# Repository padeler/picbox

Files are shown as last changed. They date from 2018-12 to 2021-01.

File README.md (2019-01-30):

# picbox
Arduino based Photo album and sketch toy. 
Simple functionality for browsing the photos on the SD card and sketching in different colors.

# Notes
In order to keep the code small enough to fit into the 28k of the arduino micro 
I stripped the TFTLCD library and kept only the functionality I needed.

The code looks for "bmp" photos in the "/album" folder of the SD Card and 
displays them starting from a random point on each boot.

Top (navigation) buttons are (from left to right) 
- show previous
- show random
- reload
- show next

Bottom buttons select the pen color for sketching.

Toy case created with OpenSCAD and printed with PLA.

## Hardware used
- Arduino pro micro (leonardo) 5V
- TF-028 TFT touch screen (240x320) shield with sd-card
- 2x18650 Batteries in series (because I had some spare)
- Power switch
- Prototyping PCB 

## External Libraries
- [TFTLCD-Library](https://github.com/adafruit/TFTLCD-Library)
- [SdFat](https://github.com/greiman/SdFat)

## Making-of Photos
PCB, arduino and LCD+touchscreen+SDCard_reader shield. Front and back views
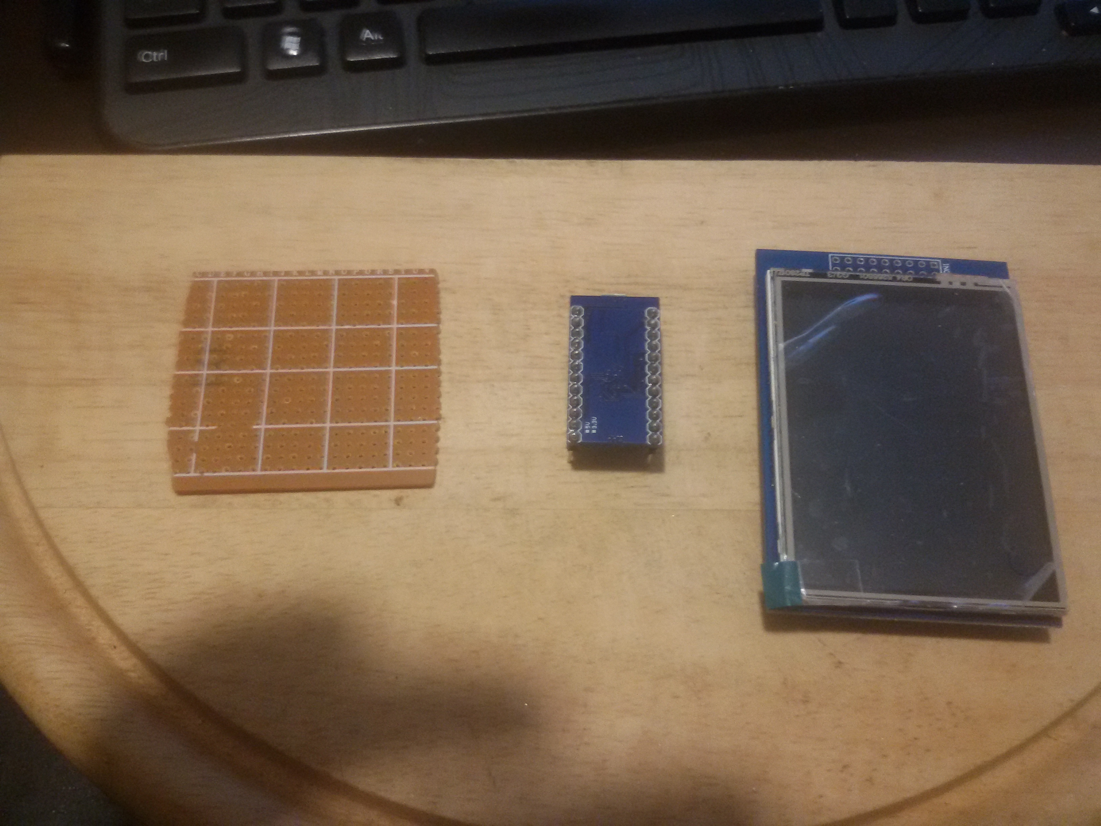
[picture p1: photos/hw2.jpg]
hw2

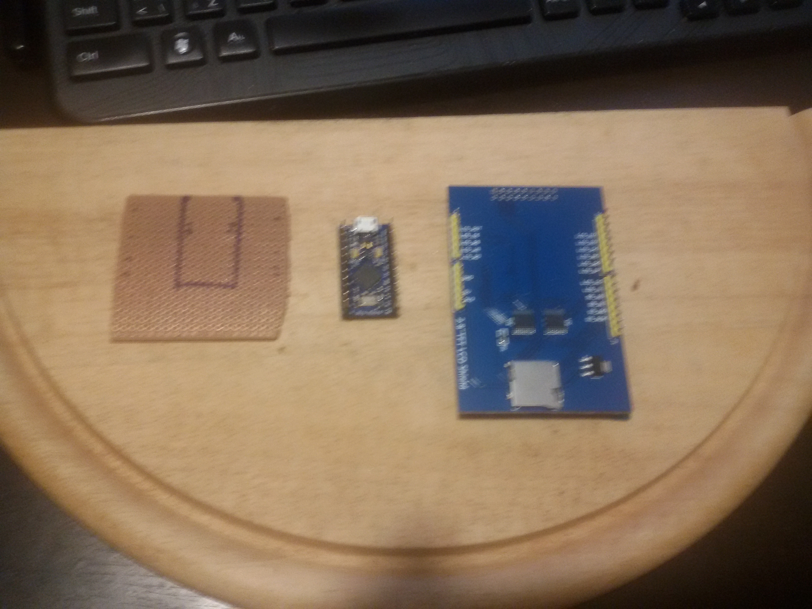
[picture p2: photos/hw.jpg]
hw

In order to save space the arduino goes between the PCB and the LCD board.
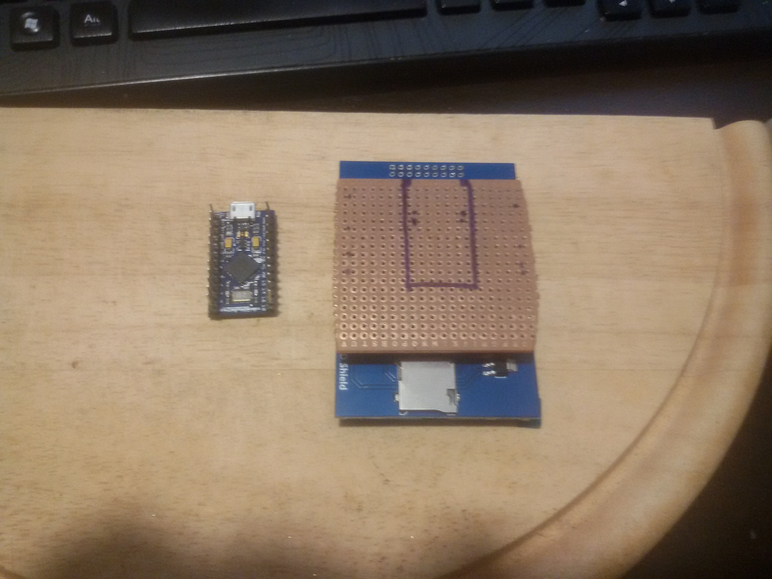
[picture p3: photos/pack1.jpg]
pack1

After soldering the arduino to the PCB. It is a bit messy but it was my first try using a PCB this way.
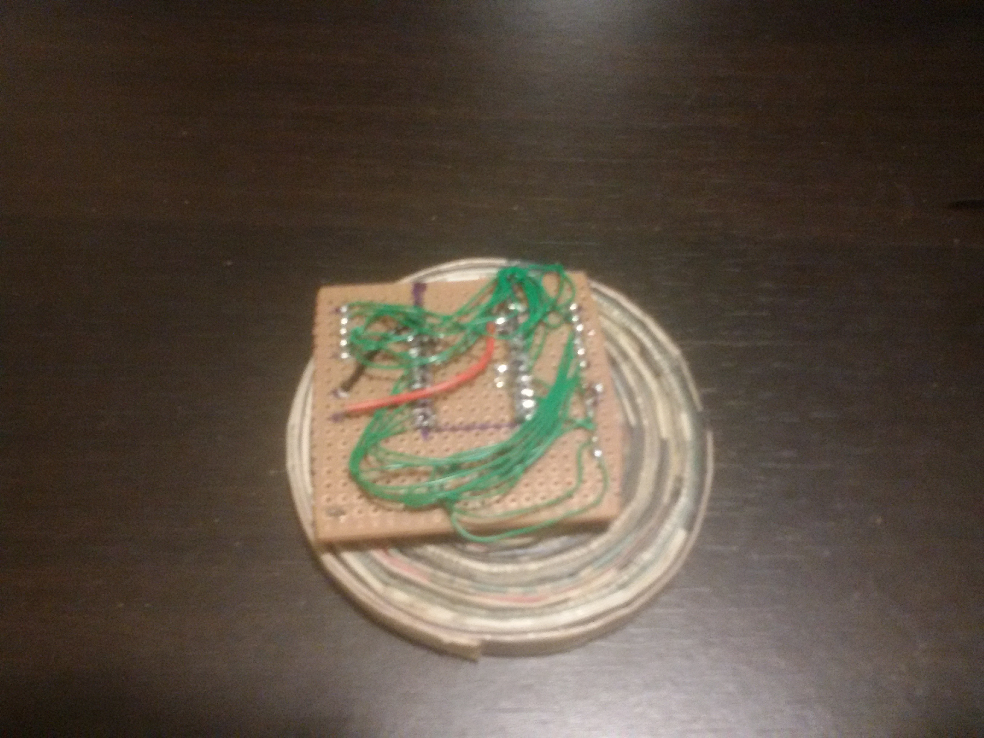
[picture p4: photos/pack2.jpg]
pack2

Testing basic h/w and s/w functionality.
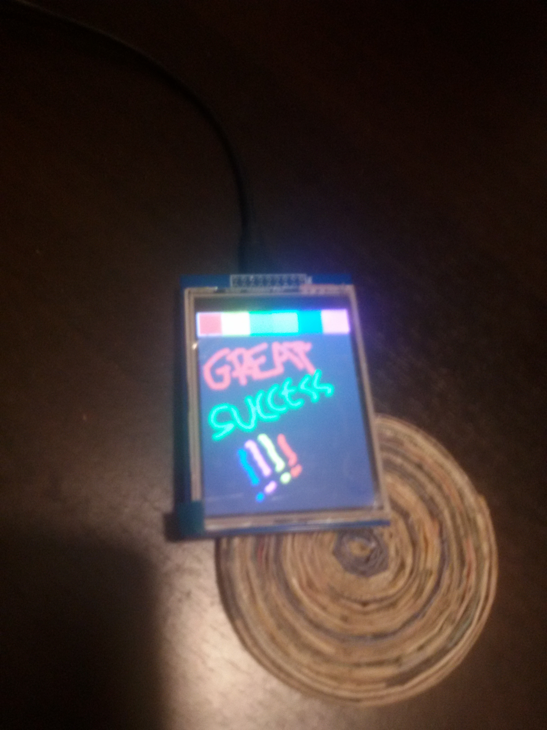
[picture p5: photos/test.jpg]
test

Assempling everything into the 3D printed case. Orange is a nice color for a little girl's toy :)
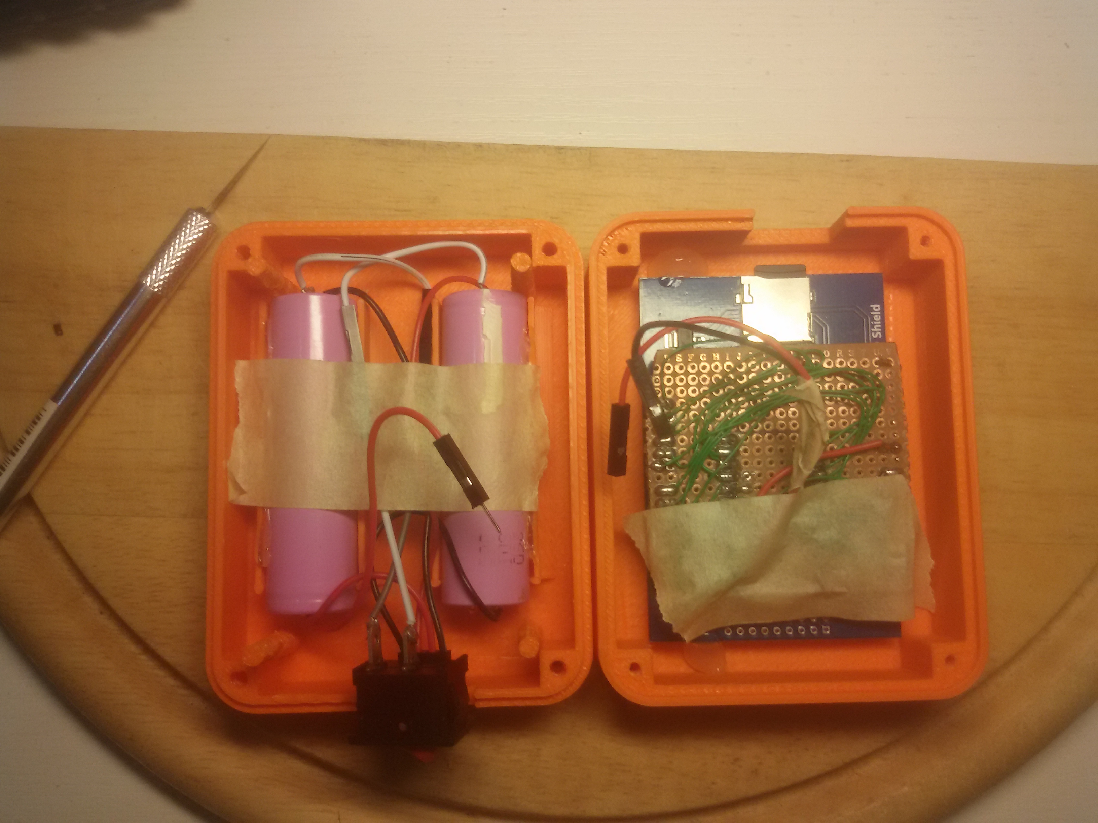
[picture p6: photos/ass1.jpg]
ass1

Another view of the box. Since this is a kids toy, I secured all h/w in place with some hot glue. Maybe it will survive a few more hits this way!
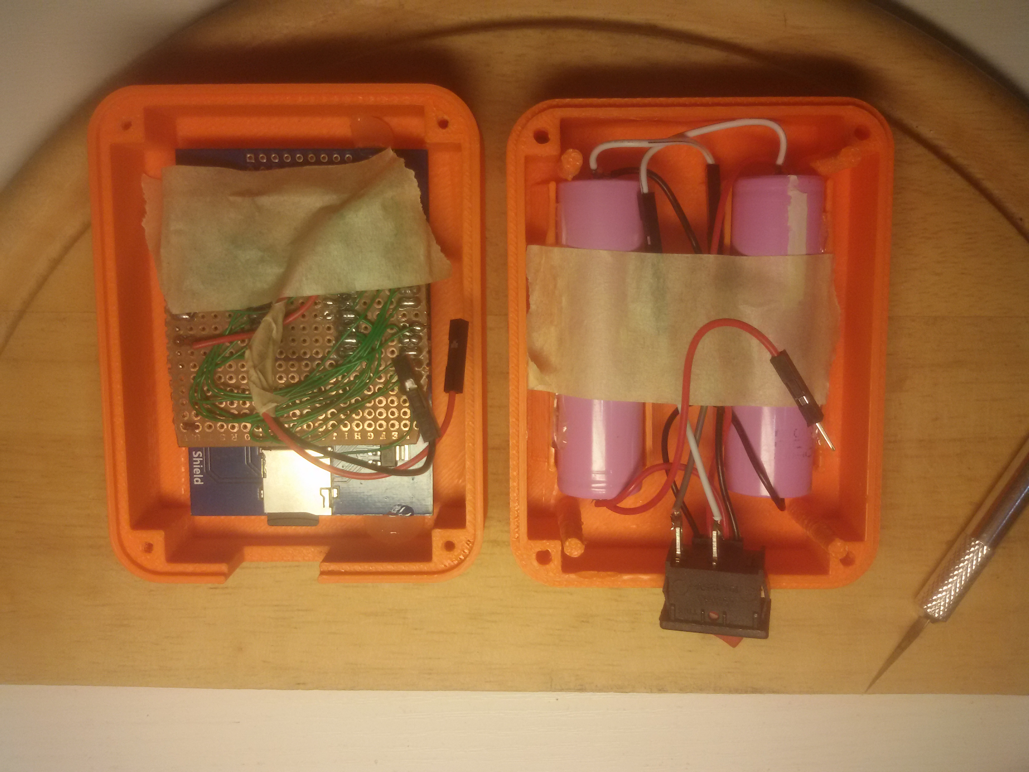
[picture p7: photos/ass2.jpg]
ass2

And this is the end result. The use of 18650 batteries made it a bit thicker than it would be if I had opted for for 2xAAA batteries and 3V H/W. But it has a pretty long battery life now!
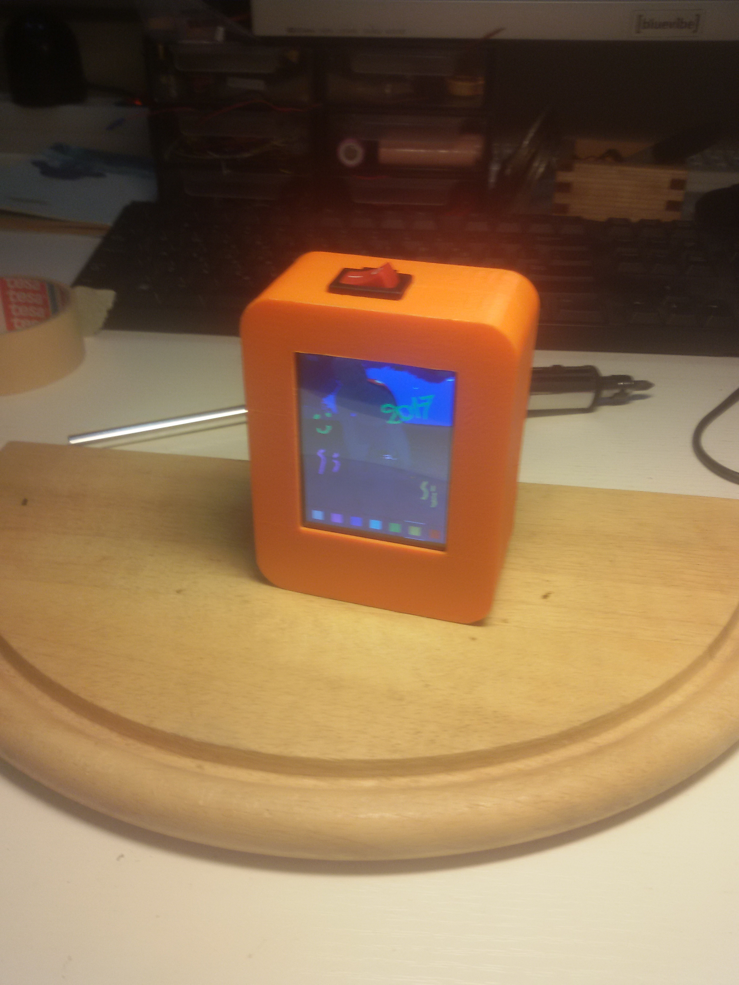
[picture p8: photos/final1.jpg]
final1
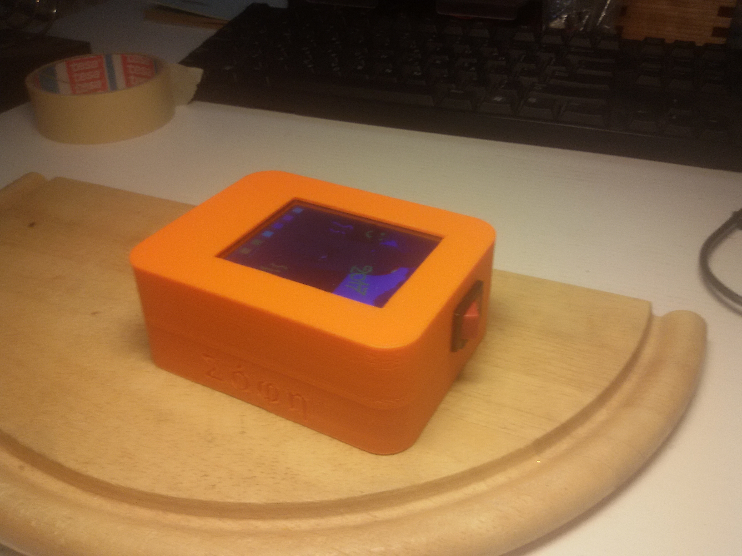
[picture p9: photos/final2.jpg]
final2
 
And a closeup of the screen showing the interface
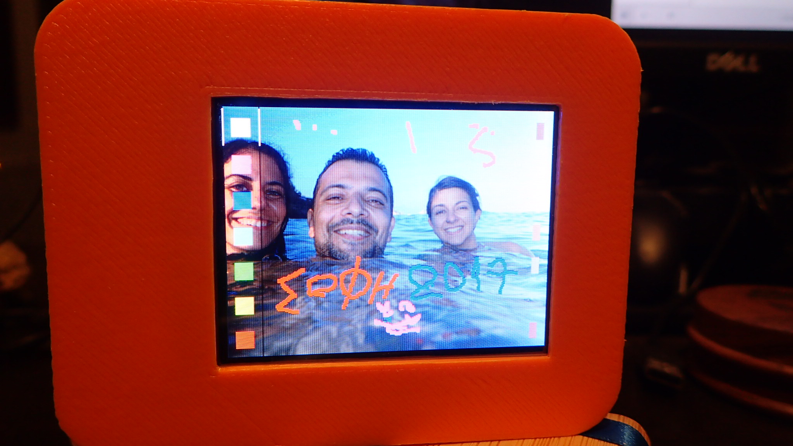
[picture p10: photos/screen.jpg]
screen


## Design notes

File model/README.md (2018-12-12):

# picbox case

The models in this folder are based on the
[3D-Printed-Case-for-Arduino](https://github.com/zygmuntw/3D-Printed-Case-for-Arduino) project.

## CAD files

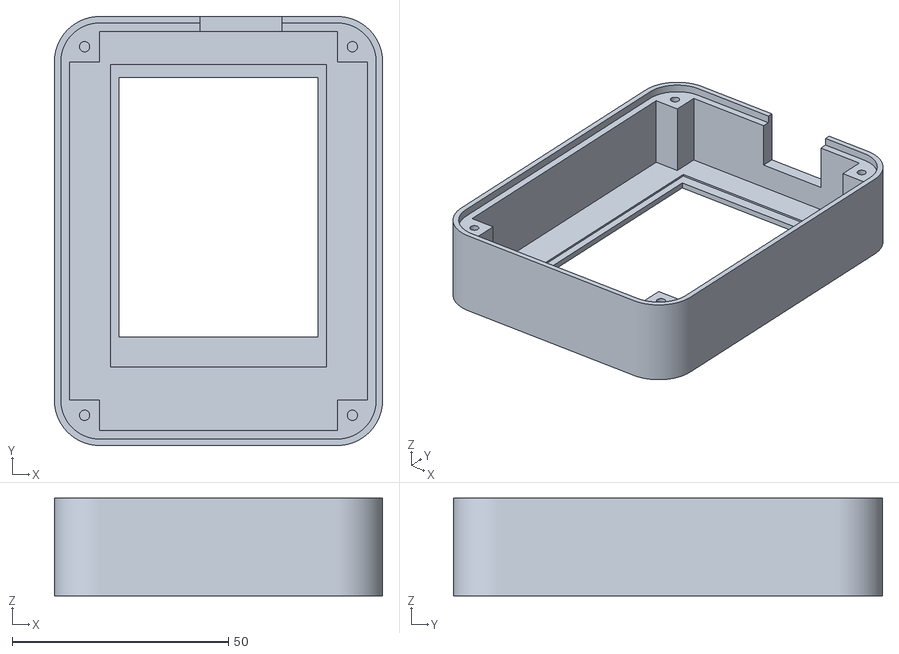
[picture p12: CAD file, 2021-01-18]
model/top.stl
76.0 x 99.3 x 22.6

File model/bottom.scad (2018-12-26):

//  ----------------------------------------------------------------------- LICENSE
//  This "3D Printed Case for Arduino Uno, Leonardo" by Zygmunt Wojcik is licensed
//  under the Creative Commons Attribution-ShareAlike 3.0 Unported License.
//  To view a copy of this license, visit
//  http://creativecommons.org/licenses/by-sa/3.0/
//  or send a letter to Creative Commons, PO Box 1866, Mountain View, CA 94042, USA.


include <common.scad>


//------------------------------------------------------------------------- MAIN BLOCK
module bottom(){
    difference()
    {
        // ADD
        union()
        {
            // Add Base
            linear_extrude(height = height/2, convexity = 10)
            minkowski()
            {									
                square([width, wide], center = true);
                circle(roundR);
            }
        }
        // SUBSTRACT
        union()
        {
            // Lift floor height
            // Cut Base hole
            translate([0, 0, floorHeight])
            linear_extrude(height = height/2, convexity = 10)
            minkowski()
            {
                square([width, wide], center = true);
                circle(roundR - pillarSize);
            }
            // Cut upper block lock
            difference() {
                translate([0, 0, height/2 - blockLockSize ]) {
                    linear_extrude(height = blockLockSize+2, convexity = 10)
                    minkowski() {
                        square([width+1, wide+1], center=true);
                        circle(roundR);
                    }
                }
                translate([0, 0, height/2 - blockLockSize ]) {
                    linear_extrude(height = blockLockSize+2, convexity = 10)
                    minkowski() {
                        square([width, wide], center=true);
                        circle(roundR - layerWidth*4);
                    }
                }
            }
                // Cut x panels 
                for (i = [0 : 180 : 180])				
                rotate([0, 0, i])
                translate([width/2 + roundR - pillarSize/2 - layerWidth*7, 0, floorHeight])
                {
                    // Cut X panel hole
                    translate([0, 0, height/2])
                    cube([pillarSize, sidePanelXWidth, height], center=true);
                    
                    // Cut X, Y srew holes
                    for (i = [wide/2, -wide/2])
                    {
                        translate([-(roundR - pillarSize/2 - layerWidth*7), i, - floorHeight])
                        if (i>0) 
                        {
                            rotate([0, 0, 45])
                            translate([screwHoleRoundR, 0, 0])
                            {
                                cylinder(h = height*2, r=screwExt/2, center=true);
                                cylinder(h = 5,
                                        r1 = (screwHead + (screwHead - screwExt))/2,
                                        r2 = screwExt/2, center=true);
                            }
                        }
                        else
                        {
                            rotate([0, 0, -45])
                            translate([screwHoleRoundR, 0, 0])
                            {
                                cylinder(h = height*2, r=screwExt/2, center=true);
                                cylinder(h = 5,
                                        r1 = (screwHead + (screwHead - screwExt))/2,
                                        r2 = screwExt/2, center=true);
                            }
                        }
                    }
                }
                // Cut Y panels 
                for (i = [90 : 180 : 270])
                rotate([0, 0, i])
                translate([wide/2 + roundR - pillarSize/2 - layerWidth*7, 0, floorHeight])
                {
                    // Cut Y panel hole
                    translate([0, 0, height/2])
                    cube([pillarSize, sidePanelYWidth, height], center=true);
                }
                
                // Cut USB and Power holes
                mirror(0,1,0)
                translate([powerHolePosX, boxLength/2, height/2 - powerHoleBottomHeight ])
                cube([powerHoleWidth, 20,  powerHoleBottomHeight+2]);

        }
    }
    
    translate([-boxWidth/2, -boxLength/2+5, floorHeight])
    batSep();
    translate([-boxWidth/2 + batteryD+4*layerWidth, -boxLength/2+5, floorHeight])
    batSep();
    
    translate([boxWidth/2 - batteryD-2*layerWidth,-boxLength/2+5,floorHeight])
    batSep();
    translate([boxWidth/2+2*layerWidth,-boxLength/2+5, floorHeight])
    batSep();
    
    translate([boxWidth/2 - 2 ,-boxLength/2 + 2,floorHeight])
    pcbLeg();

    translate([-boxWidth/2+2,-boxLength/2+2,floorHeight])
    pcbLeg();

    translate([boxWidth/2 - 2 ,boxLength/2 - 2,floorHeight])
    pcbLeg();

    translate([-boxWidth/2+2,boxLength/2-2,floorHeight])
    pcbLeg();
}

//bottom();

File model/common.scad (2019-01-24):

//  ----------------------------------------------------------------------- LICENSE
//  This "3D Printed Case for Arduino Uno, Leonardo" by Zygmunt Wojcik is licensed
//  under the Creative Commons Attribution-ShareAlike 3.0 Unported License.
//  To view a copy of this license, visit
//  http://creativecommons.org/licenses/by-sa/3.0/
//  or send a letter to Creative Commons, PO Box 1866, Mountain View, CA 94042, USA.


//------------------------------  internals (battery,board etc) 

tftRoundR = 2.54/2;

tftWide = 46;
tftLength = 60;

tftWideFull = 50;
tftLengthFull = 70;

tftPadBottom = 7; 
tftPadTop = tftLengthFull - tftLength - tftPadBottom;

tftSlotHeight = 0.5;

// 18650 cell dims
batteryD  = 18.2;
batteryRad = batteryD/2;
batteryLength = 65;

// tft+pcb+arduino assemply
boxLength=78.3;
boxWidth=55;
boxHeight=19; // total height of the assemply
tftHeight=7.2; // tft shield height 

pcbLegHeight = batteryD + boxHeight +tftSlotHeight - tftHeight ;

boxPositionX = 0;
boxPositionY = 8.7+1.8; // offset towards top

powerHoleHeight = 5 + 13.5;
powerHoleWidth = 19;
powerHolePosZ = tftHeight-tftSlotHeight;
powerHolePosX = -52.6/2 + 22;
// NOTE: a hole with height 4.5 is needed  on the bottom side
powerHoleBottomHeight = 4.5;



//------------------------------------------------------------------------- SHARED PARAMETERS
$fn=100; // resolution




circleD = 21; // round corner circle diameter
roundR = circleD/2; // round corner circle radius
triangleH = (sqrt(3)*(circleD))/2; // triangle height to calculate other variables

layerHeight = 0.25; // some variariables are multiple of layer height and width
layerWidth = 0.5;

screwExt = 3.4; // screw through hole diameter
verConnectionHoleR = 1.2; // screw thread hole radius
screwHead = 6; // screw head hole diameter

floorHeight = 2.0; // 6*0.25 layer + 0.3 first layer

height = batteryD+boxHeight+2*floorHeight; // case height
innerHeight = batteryD+boxHeight;

pillarSize = roundR-0.01; // corner pillar size

// dimensions of minkowski's inner square
// these are NOT case dimensions
// to calculate external case dimesions add 2 * roundR
// 55.3 + (2*10.5) = 76.3
width = boxWidth ;
wide = boxLength;

blockLockSize = 2; // middle connection lock size

// side cutting panels size
sidePanelXWidth = wide;
sidePanelYWidth = width;

// screw hole position from centre of the corner round circle
screwHoleRoundR = roundR - layerWidth*4 - (triangleH/2 - layerWidth*4)/2;

// prints dimensions of the case to the console
echo("width", width + roundR*2); // total width
echo("wide", wide + roundR*2); // total wide


usbHolePosition=38.1;
usbHeight=7.2 + 2;
usbWide=10.5 + 2;
powerJackPosition=7.62;
powerJackWide=8.9 +2;
powerJackHeight=10.8 +2;





//------------------------------------------------------------------COMMON MODULES
module pcbLeg() {		
    cylinder(h = pcbLegHeight, r1=5/2, r2 = 4/2);
}

module batSep(){
        cube([2*layerWidth, batteryLength-5, batteryD*2/3]);
        translate([layerWidth,0,0])
        rotate([0,-90,-90])
        linear_extrude(height = batteryLength-5, convexity = 10)
        polygon([[0,-batteryD/4],[0,batteryD/4],[batteryD/4,0]]);
}

//----------------------------------------------------------------------- FOO MODULES
module cell(){
    color([0.5,0.2,0.2])
    rotate([90,0,0])
    cylinder(batteryLength, batteryRad, batteryRad);
}

module fullbox(){
    color([0.2,0.2,0.8]) // TFT Shield  blue
    translate([-boxWidth/2,-boxLength/2,0])
    cube([boxWidth, boxLength, tftHeight]);
    color([0.2,0.5,0.2]) // PCB green
    translate([-boxWidth/2,-boxLength/2.5,tftHeight])
    cube([boxWidth, boxLength*2/3, boxHeight-tftHeight]);
}


module foo_internals1(){
    rotate([0,0,0])
    translate([0,0,floorHeight-tftSlotHeight]){
        fullbox();
        translate([-boxWidth/2 +batteryRad-1*layerWidth, boxLength/2-8,boxHeight+batteryRad])
        cell();
        translate([boxWidth/2 -batteryRad-3*layerWidth, boxLength/2-8,boxHeight+batteryRad])
        cell();

    }
}


//batSep();

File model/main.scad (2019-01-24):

include <common.scad>
include <top.scad>
include <bottom.scad>


//rotate([180,0,0])

//top();

//rotate([0,180,0])
//translate([0,0,-2*height])
difference() {
bottom();

//color([0,0,255])
translate([(boxWidth+2*roundR)/2-2*layerWidth,0,5])
rotate([90,0,90])
linear_extrude(layerWidth*3)
text("Σόφη",halign="center", spacing=1.3);
}
//
//foo_internals1();

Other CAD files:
model/top.scad

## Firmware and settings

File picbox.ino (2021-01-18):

// Paint example specifically for the TFTLCD breakout board.
// If using the Arduino shield, use the tftpaint_shield.pde sketch instead!
// DOES NOT CURRENTLY WORK ON ARDUINO LEONARDO

#include <SPI.h>
#include "src/tft/Adafruit_TFTLCD.h" // Hardware-specific library
#include <TouchScreen.h>

// next line for SD.h
//#include <SD.h>

#include <SdFat.h>
SdFat SD;

#if defined(__SAM3X8E__)
#undef __FlashStringHelper::F(string_literal)
#define F(string_literal) string_literal
#endif

#define YP A3 // must be an analog pin, use "An" notation!
#define XM A2 // must be an analog pin, use "An" notation!
#define YM 9  // can be a digital pin
#define XP 8  // can be a digital pin

#define TS_MINX 248
#define TS_MAXX 435
#define TS_MINY 102
#define TS_MAXY 900

// (partial) fix for my broken touchscreen 
#define TS_MINX2 150
#define TS_MAXX2 550


// For better pressure precision, we need to know the resistance
// between X+ and X- Use any multimeter to read it
// For the one we're using, its 300 ohms across the X plate
TouchScreen ts = TouchScreen(XP, YP, XM, YM, 300);

#define LCD_CS A3
#define LCD_CD A2
#define LCD_WR A1
#define LCD_RD A0
// optional
#define LCD_RESET A4

#define SD_CS 10 // Set the chip select line to whatever you use (10 doesnt conflict with the library)

// Assign human-readable names to some common 16-bit color values:
#define BLACK 0x0000
#define BLUE 0x001F
#define RED 0xF800
#define GREEN 0x07E0
#define CYAN 0x07FF
#define MAGENTA 0xF81F
#define YELLOW 0xFFE0
#define WHITE 0xFFFF
#define BC1 0xAAAA
#define BC2 0xBBBB
#define BC3 0xCCCC


Adafruit_TFTLCD tft(LCD_CS, LCD_CD, LCD_WR, LCD_RD, LCD_RESET);

#define BOXSIZE 34
#define PENRADIUS 3

#define ALBUM "/album"
uint16_t oldcolor, currentcolor;
uint16_t total_images;

uint16_t current_image;

File album;
bool repaint;

bool seed_needed = true;

void setup(void)
{
  // // initialize digital pin LED_BUILTIN as an output.
  // pinMode(LED_BUILTIN, OUTPUT);
  // digitalWrite(LED_BUILTIN, HIGH);   // turn the LED on (HIGH is the voltage level)
  // delay(500);                       // wait for a second
  // digitalWrite(LED_BUILTIN, LOW);    // turn the LED off by making the voltage LOW

  Serial.begin(9600);
  Serial.println(F("Starting Paint!"));

  tft.reset();

  uint16_t identifier = 0x9341; //tft.readID();

  // if(identifier == 0x9325) {
  //   Serial.println(F("Found ILI9325 LCD driver"));
  // } else if(identifier == 0x9328) {
  //   Serial.println(F("Found ILI9328 LCD driver"));
  // } else if(identifier == 0x7575) {
  //   Serial.println(F("Found HX8347G LCD driver"));
  // } else if(identifier == 0x9341) {
  //   Serial.println(F("Found ILI9341 LCD driver"));
  // } else if(identifier == 0x8357) {
  //   Serial.println(F("Found HX8357D LCD driver"));
  // } else {
  //   Serial.print(F("Unknown LCD driver chip: "));
  //   Serial.println(identifier, HEX);
  //   Serial.println(F("If using the Adafruit 2.8\" TFT Arduino shield, the line:"));
  //   Serial.println(F("  #define USE_ADAFRUIT_SHIELD_PINOUT"));
  //   Serial.println(F("should appear in the library header (Adafruit_TFT.h)."));
  //   Serial.println(F("If using the breakout board, it should NOT be #defined!"));
  //   Serial.println(F("Also if using the breakout, double-check that all wiring"));
  //   Serial.println(F("matches the tutorial."));
  //   return;
  // }

  tft.begin(identifier);

  tft.fillScreen(BLACK);

  // Serial.print(F("Initializing SD card..."));
  if (!SD.begin(SD_CS))
  {
    // Serial.println(F("failed!"));
    return;
  }
  // Serial.println(F("OK!") );

  // // bmpDraw("/test.bmp");

  repaint = true;
  if(!(album = SD.open(ALBUM)))
  {
    return; // failed to open album folder
  }

  total_images = count_files(&album);
  current_image = 0; //random(total_images);
  pinMode(13, OUTPUT);
}

#define MINPRESSURE 10
#define MAXPRESSURE 1000

void loop()
{
  // delay(100);
  paint_loop();
}

uint16_t count_files(File *dir)
{
  dir->rewind();
  uint16_t res=0;
  File f;
  while(f.openNext(dir, O_READ))
  {
    if (f.isFile())
    {
      res++;
    }
    f.close();
  }
  return res;
}

File open_file(File *dir, uint16_t index)
{
  uint16_t pos = 0;
  dir->rewind();
  File res;
  while(pos<=index && res.openNext(dir, O_READ)) 
  {
    if(res.isFile())
    {
      if(pos==index){
        return res;
      }
      pos++;
    }
    res.close();
  }
}


void paint_buttons(uint8_t selected)
{

  // top buttons
  tft.fillRect(0         + BOXSIZE/4, tft.height() - BOXSIZE/2, BOXSIZE/2, BOXSIZE/4, BC1);
  tft.fillRect(BOXSIZE*2 + BOXSIZE/4, tft.height() - BOXSIZE/2, BOXSIZE/2, BOXSIZE/4, BC2);
  tft.fillRect(BOXSIZE*3 + BOXSIZE/4, tft.height() - BOXSIZE/2, BOXSIZE/2, BOXSIZE/4, BC3);
  tft.fillRect(BOXSIZE*6 + BOXSIZE/4, tft.height() - BOXSIZE/2, BOXSIZE/2, BOXSIZE/4, BC1);


  // bottom buttons
  tft.fillRect(0         + BOXSIZE/4, 0 + BOXSIZE/4, BOXSIZE/2, BOXSIZE/2, RED);
  tft.fillRect(BOXSIZE   + BOXSIZE/4, 0 + BOXSIZE/4, BOXSIZE/2, BOXSIZE/2, YELLOW);
  tft.fillRect(BOXSIZE*2 + BOXSIZE/4, 0 + BOXSIZE/4, BOXSIZE/2, BOXSIZE/2, GREEN);
  tft.fillRect(BOXSIZE*3 + BOXSIZE/4, 0 + BOXSIZE/4, BOXSIZE/2, BOXSIZE/2, CYAN);
  tft.fillRect(BOXSIZE*4 + BOXSIZE/4, 0 + BOXSIZE/4, BOXSIZE/2, BOXSIZE/2, BLUE);
  tft.fillRect(BOXSIZE*5 + BOXSIZE/4, 0 + BOXSIZE/4, BOXSIZE/2, BOXSIZE/2, MAGENTA);
  tft.fillRect(BOXSIZE*6 + BOXSIZE/4, 0 + BOXSIZE/4, BOXSIZE/2, BOXSIZE/2, WHITE);
  tft.drawFastHLine(0, 0, tft.width(), BLACK);
  tft.drawFastHLine(0, BOXSIZE-1, tft.width(), BLACK);

  tft.drawFastHLine(BOXSIZE*selected, 0, BOXSIZE, WHITE);
  tft.drawFastHLine(BOXSIZE*selected, BOXSIZE-1, BOXSIZE, WHITE);

  // tft.fillRect(0, tft.height()-3, tft.width(), 3, WHITE);
}

void paint_loop()
{
  if (repaint)
  {
    // XXX No need to clear screen if all album images are qvga
    // tft.fillRect(0, BOXSIZE, tft.width(), tft.height()-BOXSIZE, BLACK);

    File bmpFile = open_file(&album, current_image);
    if (bmpFile.isFile())
    {
      bmpDraw(bmpFile);
    }

    bmpFile.close();

    currentcolor = RED;
    paint_buttons(0);

    repaint = false;
  }

  digitalWrite(13, HIGH);
  TSPoint p = ts.getPoint();
  digitalWrite(13, LOW);


  // if sharing pins, you'll need to fix the directions of the touchscreen pins
  //pinMode(XP, OUTPUT);
  pinMode(XM, OUTPUT);
  pinMode(YP, OUTPUT);
  //pinMode(YM, OUTPUT);

  // we have some minimum pressure we consider 'valid'
  // pressure of 0 means no pressing!

  if(p.z > MINPRESSURE && p.z < MAXPRESSURE)
  {
    if(seed_needed)
    {
        randomSeed(p.x+p.y+p.z);
        seed_needed=false;
    }
    Serial.print(F("RAW "));
    Serial.print(p.x);Serial.print(" ");
    Serial.print(p.y);Serial.print(" ");

    p.y = map(p.y, TS_MINY, TS_MAXY, 0, tft.height());
    p.y = constrain(p.y, 0 , tft.height());

    if(p.y<60 || p.y>230)
    { // PPP Broken touch screen: On the edges use different mapping for p.x
      p.x = map(p.x, TS_MINX2, TS_MAXX2, 0, tft.width());  
    }
    else
    {
      p.x = map(p.x, TS_MINX, TS_MAXX, 0, tft.width());
    }

    p.x = constrain(p.x, 0 , tft.width());
    
    Serial.print(F("MAP "));
    Serial.print(p.x);Serial.print(" ");
    Serial.print(p.y);Serial.println(" ");

    // y is inverted for some reason in the tft lib.
    p.y = tft.height() - p.y; 

    if(p.y>tft.height()-BOXSIZE)
    { // top buttons
      uint8_t m = p.x / BOXSIZE;
      switch(m)
      {
        case 0: // right button 
          current_image = (current_image+1)%total_images;
          repaint=true;
          break;
        case 1:
          break;
        case 2: //  button, repaint
          repaint=true;
          break;
        case 3: //  , random image
          randomSeed(millis());
          current_image = random(total_images);
          repaint=true;
          break;
        case 4:
          break;
        case 6: // left button
          current_image>0?current_image = current_image-1:current_image=total_images-1;
          repaint=true;
          break;
      }      
    }


    if (p.y < BOXSIZE)
    {
      oldcolor = currentcolor;
      uint8_t m = p.x / BOXSIZE;
      paint_buttons(m);

      switch(m)
      {
        case 0:
          currentcolor = RED;
          break;
        case 1:
          currentcolor = YELLOW;
          break;
        case 2:
          currentcolor = GREEN;
          break;
        case 3:
          currentcolor = CYAN;
          break;
        case 4:
          currentcolor = BLUE;
          break;
        case 5:
          currentcolor = MAGENTA;
          break;
        default:
          currentcolor = WHITE;
      }
    }
    if (((p.y - PENRADIUS) > BOXSIZE) && ((p.y + PENRADIUS) < tft.height()))
    { // paint
      // tft.drawPixel(p.x, p.y, currentcolor);
      tft.fillRect(p.x, p.y, PENRADIUS, PENRADIUS, currentcolor);
    }
  }
}

#define RGB_BUF_SIZE 48
#define BMP_HEADER_LEN 34

bool read(File &f, uint8_t *buf, int len)
{
  int rcv=0;
  while(rcv!=len)
  {
    int got = f.read(buf+rcv, len-rcv);
    if(got==-1) return false;
    rcv+=got;
  }
  return true;
}

void bmpDraw(File &bmpFile)
{

  uint8_t *rgb = (uint8_t*)malloc(RGB_BUF_SIZE);

  // read full bmp header
  if(read(bmpFile, rgb, BMP_HEADER_LEN))
  {
    if(*((uint16_t*)(rgb+0)) == 0x4D42 && // bmp signature
      *((uint16_t*)(rgb+2+4+4+4+4+4+4)) == 1 && // planes==1
      *((uint16_t*)(rgb+2+4+4+4+4+4+4+2)) == 24 && // depth==24
      *((uint32_t*)(rgb+2+4+4+4+4+4+4+2+2)) == 0) // 0==uncompressed
    {
      uint32_t bmpImageoffset = *((uint32_t*)(rgb+2+4+4)); // offset
      uint32_t bmpWidth       = *((uint32_t*)(rgb+2+4+4+4+4)); // width
      uint32_t bmpHeight      = *((uint32_t*)(rgb+2+4+4+4+4+4)); // height

      if (bmpHeight < 0)
      {
        // If bmpHeight is negative, image is in top-down order.
        // This is not canon but has been observed in the wild.
        bmpHeight = -bmpHeight;
      }
      // Set TFT address window to clipped image bounds
      tft.setAddrWindow(0, 0, bmpWidth, bmpHeight);

      // BMP rows are padded (if needed) to 4-byte boundary
      uint32_t padSize = ((bmpWidth * 3 + 3) & ~3)-3*bmpWidth;

      uint32_t pos = 0; 
      bmpFile.seek(bmpImageoffset);
      while(pos<bmpWidth*bmpHeight)
      {
        uint8_t step = min((bmpWidth-pos%bmpWidth)*3, RGB_BUF_SIZE);
        // read step bytes
        if(!read(bmpFile, rgb, step)) 
        {
          break;
        }
        // convert inplace to 16bit pixels and send to TFT
        uint8_t j=0;
        for(uint8_t i=0;i<step;i+=3)
        {
          ((uint16_t*)rgb)[j] = tft.color565(rgb[i+2], rgb[i+1], rgb[i+0]);
          j++;
        }
        tft.pushColors(((uint16_t*)rgb), j, pos==0);

        pos+=step/3;
        if(pos%bmpWidth==0){  // skip padding
          bmpFile.seekCur(padSize);
        }
      }
    }
  }

  free(rgb);
}

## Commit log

2018-12-12 picbox initial commit
    [bottom.scad, common.scad, main.scad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]
2018-12-12 remove unused old model parts
    [bottom.scad, common.scad, main.scad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]
2018-12-26 draft1 of the scad model
    [bottom.scad, common.scad, main.scad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]
2019-01-07 Small fix on the screen hole location.
    [common.scad, main.scad, top.scad]
2019-01-24 More support for batsep. Added name engraving on side
    [common.scad, main.scad]
2019-11-03 Fixes random seed with millis
    [picbox.ino]
2021-01-18 Switching to vscode arduino plugin. Move main sketch to root
    [top.stl]
2021-01-18 S/W Fix (partial) for my broken touchscreen
    [picbox.ino]
